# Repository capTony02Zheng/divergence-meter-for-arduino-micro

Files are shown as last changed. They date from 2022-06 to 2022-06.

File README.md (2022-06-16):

# divergence-meter-for-arduino-micro
 This is a project use for creating an divergence meter. Thank you for visiting.
-----------------------------------------------------------------------

 Code are well written but need the user to update the IRdata to match the 1838IR remote control. Also the ds3231 module need to be updated with
other code, which is not provided here.

 The PCB is developed with kiCAD.

 To start up from nothing, here's the few steps you need to follow:
-----------------------------------------------------------------------
 Get all the component you need, which includes:

// An arduino micro board;
// A pcb that is printed with the file provided; (this pcb is 51mm * 130mm in size)
// A ds3231 time module;
// An IR1838 module with corresponding remote control;
// One or two 5v to 170v boost module;
// multiple resistors of 10k and 100k;
// four hv5523pg-g chips; you can buy some here: https://www.microchip.com/en-us/product/hv5522#document-table;

After gathering all the component, it is time for you to do the soldering work. It is recommended to solder the 4 chips first, then the arduino board.

About the boost module:
pin "170vin1" and "170vin2" should be connected to the 170v output from the boost module. pin "5VFB" shoule be connected to the 5v input on the boost module.

About external power source(Optional):
if you decided to use other battery module to support the arduino, the pins "BatteryIn" and "BatteryGround" is provided, the supporting volts should not exceeds the the range that arduino micro can accept.

About the resistors:
It is recommended to connect 10k or 20k resistors at the pins "170V" and "170V2";
for places like "t1dp" and "t2dp", a 100k resistor is recommended.

About the pins:
you can directly connected the nixie tubes pins to the correponding hole in the pcb, like the t1n1 means tube1 number1, at displays it is the number "1" of the left most nixie tube. or you can use ph2.0 sockets with 12 pins.

Features and controls of the divergence meter:
-----------------------------------------------------------------------
There are 6 mode for the divergence meter, the first one displays current time; the second one displays current date; the third one
displays Celsius temperature recorded by ds3231; the fourth mode displays displays worldline; the fifth mode displays the number you entered;
the sixth one diplays number from 0 to 9 to protect the tubes;

//About the control:

Power: close or open;

Menu: First time you pressed you entered menu mode, then you can push button from 0 to 5 to choose corresponding mode, which will help you leave the menu mode automatically. Or at menu mode you can use arrow to go to the next or previous mode, then press menu again to exit the menu mode;

Play: At worldline mode you can use it to get in and out of random display mode; At manual input mode you can use it to open or close displays.

"-": as decimal point in manual input mode.

"C": At manual input mode you can use it to change wether the decimal point and number are display in one tube or not, which can save some spaces. At worldline mode you can change the number to be displayed one by one or all by instant.

"return": clear all the input data at the manual display mode.

left and right arrow: when at worldline mode and the menu mode is off, you can use it to display the next or previous worldline.

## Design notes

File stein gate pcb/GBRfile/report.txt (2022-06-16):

Plotted to '/Users/zzh/Desktop/kicad project/stein gate pcb/GBRfile/stein gate pcb-F_Cu.gbr'.
Plotted to '/Users/zzh/Desktop/kicad project/stein gate pcb/GBRfile/stein gate pcb-B_Cu.gbr'.
Plotted to '/Users/zzh/Desktop/kicad project/stein gate pcb/GBRfile/stein gate pcb-F_Paste.gbr'.
Plotted to '/Users/zzh/Desktop/kicad project/stein gate pcb/GBRfile/stein gate pcb-B_Paste.gbr'.
Plotted to '/Users/zzh/Desktop/kicad project/stein gate pcb/GBRfile/stein gate pcb-F_Silkscreen.gbr'.
Plotted to '/Users/zzh/Desktop/kicad project/stein gate pcb/GBRfile/stein gate pcb-B_Silkscreen.gbr'.
Plotted to '/Users/zzh/Desktop/kicad project/stein gate pcb/GBRfile/stein gate pcb-F_Mask.gbr'.
Plotted to '/Users/zzh/Desktop/kicad project/stein gate pcb/GBRfile/stein gate pcb-B_Mask.gbr'.
Plotted to '/Users/zzh/Desktop/kicad project/stein gate pcb/GBRfile/stein gate pcb-Edge_Cuts.gbr'.
Created Gerber job file '/Users/zzh/Desktop/kicad project/stein gate pcb/GBRfile/stein gate pcb-job.gbrjob'.
Info: Done.

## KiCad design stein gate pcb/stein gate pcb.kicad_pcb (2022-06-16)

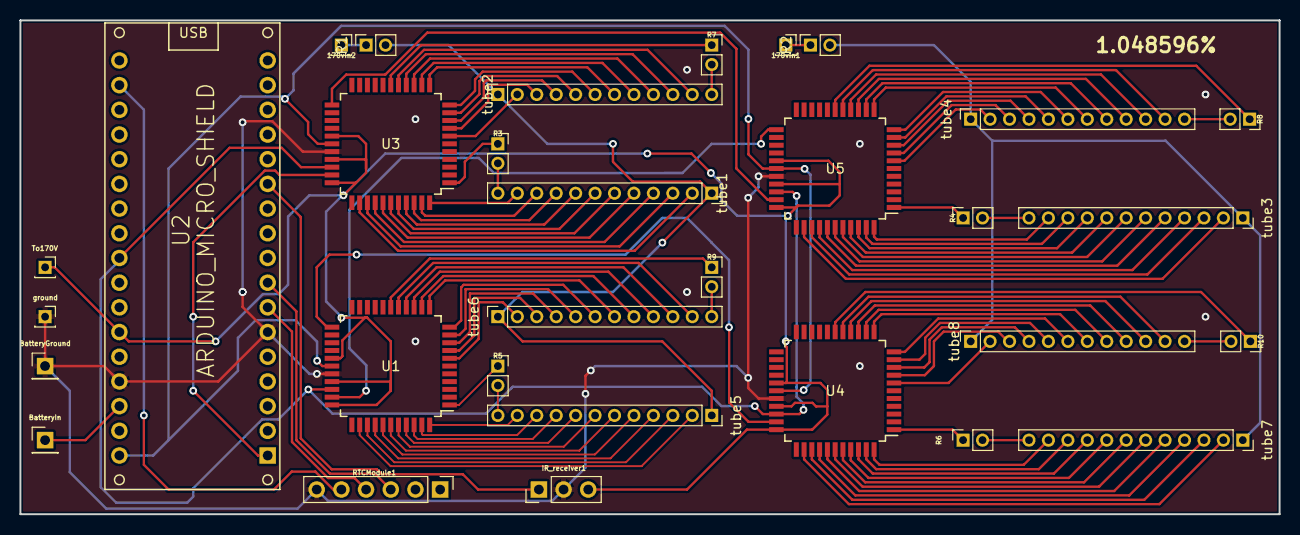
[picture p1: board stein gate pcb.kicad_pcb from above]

Board: 2 copper layers, 129.5 x 50.8 mm, 31 parts (0 on the bottom side), 113 nets.

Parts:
170vin1, 170vin2: Conn_01x01_Female; PinSocket_1x01_P2.00mm_Vertical
BatteryGround: Conn_01x01_Female; PinHeader_1x01_P2.54mm_Vertical
BatteryIn: Conn_01x01_Female; PinHeader_1x01_P2.54mm_Vertical
IR_receiver1: Conn_01x03_Female; PinHeader_1x03_P2.54mm_Vertical
R1, R2, R3, R4, R5, R6, R7, R8, R9, R10: R; PinSocket_1x02_P2.00mm_Vertical
RTCModule1: Conn_01x06_Female; PinHeader_1x06_P2.54mm_Vertical
To170V: Conn_01x01_Female; PinSocket_1x01_P2.00mm_Vertical
U1, U3, U4, U5: hv5522(first_created); PQFP-44_10x10mm_P0.8mm
U2: ARDUINO_MICRO_SHIELD
ground: Conn_01x01_Female; PinSocket_1x01_P2.00mm_Vertical
tube1, tube2, tube3, tube4, tube5, tube6, tube7, tube8: ph2.0_terminal_for_5440; PinSocket_1x12_P2.00mm_Vertical

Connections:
/3.3VFB: RTCModule1.5, U2.3.3V
/5VFB: IR_receiver1.3, To170V.1, U1.27 (POL), U1.30 (VDD), U1.33 (BL), U2.5V (+5V), U3.27 (POL), U3.30 (VDD), U3.33 (BL), U4.27 (POL), U4.30 (VDD), U4.33 (BL), U5.27 (POL), U5.30 (VDD), U5.33 (BL)
/170V: R2.2, tube3.1, tube4.1, tube7.1, tube8.1
/170V2: R1.2, tube1.1, tube2.1, tube5.1, tube6.1
/Clock: U1.28 (CLK), U2.SCK, U3.28 (CLK), U4.28 (CLK), U5.28 (CLK)
/DataFromBoard: U2.MO (MOSI), U3.32 (Data_in)
/IRdata: IR_receiver1.1, U2.7
/SCL: RTCModule1.3, U2.3 (3(PWM)/SCL)
/SDA: RTCModule1.4, U2.2 (2/SDA)
/dataout1: U3.23 (Data_out), U5.32 (Data_in)
/dataout2: U1.32 (Data_in), U5.23 (Data_out)
/dataout3: U1.23 (Data_out), U4.32 (Data_in)
/latch: U1.31 (Latch_), U2.A5, U3.31 (Latch_), U4.31 (Latch_), U5.31 (Latch_)
/t1dp: R3.1, U3.1 (HVOUT_11)
/t1n0: U3.44 (HVOUT_10), tube1.11
/t1n1: U3.35 (HVOUT_1), tube1.2
/t1n2: U3.36 (HVOUT_2), tube1.3
/t1n3: U3.37 (HVOUT_3), tube1.4
/t1n4: U3.38 (HVOUT_4), tube1.5
/t1n5: U3.39 (HVOUT_5), tube1.6
/t1n6: U3.40 (HVOUT_6), tube1.7
/t1n7: U3.41 (HVOUT_7), tube1.8
/t1n8: U3.42 (HVOUT_8), tube1.9
/t1n9: U3.43 (HVOUT_9), tube1.10
/t2dp: R7.1, U3.17 (HVOUT_27)
/t2n0: U3.16 (HVOUT_26), tube2.11
/t2n1: U3.7 (HVOUT_17), tube2.2
/t2n2: U3.8 (HVOUT_18), tube2.3
/t2n3: U3.9 (HVOUT_19), tube2.4
/t2n4: U3.10 (HVOUT_20), tube2.5
/t2n5: U3.11 (HVOUT_21), tube2.6
/t2n6: U3.12 (HVOUT_22), tube2.7
/t2n7: U3.13 (HVOUT_23), tube2.8
/t2n8: U3.14 (HVOUT_24), tube2.9
/t2n9: U3.15 (HVOUT_25), tube2.10
/t3dp: R4.1, U5.1 (HVOUT_11)
/t3n0: U5.44 (HVOUT_10), tube3.11
/t3n1: U5.35 (HVOUT_1), tube3.2
/t3n2: U5.36 (HVOUT_2), tube3.3
/t3n3: U5.37 (HVOUT_3), tube3.4
/t3n4: U5.38 (HVOUT_4), tube3.5
/t3n5: U5.39 (HVOUT_5), tube3.6
/t3n6: U5.40 (HVOUT_6), tube3.7
/t3n7: U5.41 (HVOUT_7), tube3.8
/t3n8: U5.42 (HVOUT_8), tube3.9
/t3n9: U5.43 (HVOUT_9), tube3.10
/t4dp: R8.1, U5.17 (HVOUT_27)
/t4n0: U5.16 (HVOUT_26), tube4.11
/t4n1: U5.7 (HVOUT_17), tube4.2
/t4n2: U5.8 (HVOUT_18), tube4.3
/t4n3: U5.9 (HVOUT_19), tube4.4
/t4n4: U5.10 (HVOUT_20), tube4.5
/t4n5: U5.11 (HVOUT_21), tube4.6
/t4n6: U5.12 (HVOUT_22), tube4.7
/t4n7: U5.13 (HVOUT_23), tube4.8
/t4n8: U5.14 (HVOUT_24), tube4.9
/t4n9: U5.15 (HVOUT_25), tube4.10
/t5dp: R5.1, U1.1 (HVOUT_11)
/t5n0: U1.44 (HVOUT_10), tube5.11
/t5n1: U1.35 (HVOUT_1), tube5.2
/t5n2: U1.36 (HVOUT_2), tube5.3
/t5n3: U1.37 (HVOUT_3), tube5.4
/t5n4: U1.38 (HVOUT_4), tube5.5
/t5n5: U1.39 (HVOUT_5), tube5.6
/t5n6: U1.40 (HVOUT_6), tube5.7
/t5n7: U1.41 (HVOUT_7), tube5.8
/t5n8: U1.42 (HVOUT_8), tube5.9
/t5n9: U1.43 (HVOUT_9), tube5.10
/t6dp: R9.1, U1.17 (HVOUT_27)
/t6n0: U1.16 (HVOUT_26), tube6.11
/t6n1: U1.7 (HVOUT_17), tube6.2
/t6n2: U1.8 (HVOUT_18), tube6.3
/t6n3: U1.9 (HVOUT_19), tube6.4
/t6n4: U1.10 (HVOUT_20), tube6.5
/t6n5: U1.11 (HVOUT_21), tube6.6
/t6n6: U1.12 (HVOUT_22), tube6.7
/t6n7: U1.13 (HVOUT_23), tube6.8
/t6n8: U1.14 (HVOUT_24), tube6.9
/t6n9: U1.15 (HVOUT_25), tube6.10
/t7dp: R6.1, U4.1 (HVOUT_11)
/t7n0: U4.44 (HVOUT_10), tube7.11
/t7n1: U4.35 (HVOUT_1), tube7.2
/t7n2: U4.36 (HVOUT_2), tube7.3
/t7n3: U4.37 (HVOUT_3), tube7.4
/t7n4: U4.38 (HVOUT_4), tube7.5
/t7n5: U4.39 (HVOUT_5), tube7.6
/t7n6: U4.40 (HVOUT_6), tube7.7
/t7n7: U4.41 (HVOUT_7), tube7.8
/t7n8: U4.42 (HVOUT_8), tube7.9
/t7n9: U4.43 (HVOUT_9), tube7.10
/t8dp: R10.1, U4.17 (HVOUT_27)
/t8n0: U4.16 (HVOUT_26), tube8.11
/t8n1: U4.7 (HVOUT_17), tube8.2
/t8n2: U4.8 (HVOUT_18), tube8.3
/t8n3: U4.9 (HVOUT_19), tube8.4
/t8n4: U4.10 (HVOUT_20), tube8.5
/t8n5: U4.11 (HVOUT_21), tube8.6
/t8n6: U4.12 (HVOUT_22), tube8.7
/t8n7: U4.13 (HVOUT_23), tube8.8
/t8n8: U4.14 (HVOUT_24), tube8.9
/t8n9: U4.15 (HVOUT_25), tube8.10
GND: BatteryGround.1, IR_receiver1.2, RTCModule1.6, U1.29 (VSS(GND)), U2.GND, U3.29 (VSS(GND)), U4.29 (VSS(GND)), U5.29 (VSS(GND)), ground.1
unnamed: 170vin1.1, R2.1
unnamed: 170vin2.1, R1.1
unnamed: BatteryIn.1, U2.VI (VIN)
unnamed: R3.2, tube1.12
unnamed: R7.2, tube2.12
unnamed: R4.2, tube3.12
unnamed: R8.2, tube4.12
unnamed: R5.2, tube5.12
unnamed: R9.2, tube6.12
unnamed: R6.2, tube7.12
unnamed: R10.2, tube8.12

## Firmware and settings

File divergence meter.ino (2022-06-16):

// By capTOZ.
// These are code worked for the divergence meter that published in github.
// For use, the ds3231 module need to be updated, which is not included in these code.
// All you need to update is the translateIR() function, you need to update the case to the corresponding button.
// 用中文就长话短说了。这是给世界线变动率探测仪的代码，ds3231时钟模块的更改时间设定请另寻代码来更新。
// 同时translateIR()这个function需要更新才可以使变动率探测仪正常接收遥控器信号。

#include <SPI.h>
#include "RTClib.h"
#include <Wire.h>
#include "IRremote.h"

#define num1 0x8000
#define num2 0x4000
#define num3 0x2000
#define num4 0x1000
#define num5 0x0800
#define num6 0x0400
#define num7 0x0200
#define num8 0x0100
#define num9 0x0080
#define num0 0x0040
#define decimalpoint 0x0020 
#define no_display 0x0000

#define num1dot 0x8020
#define num2dot 0x4020
#define num3dot 0x2020
#define num4dot 0x1020
#define num5dot 0x0820
#define num6dot 0x0420
#define num7dot 0x0220
#define num8dot 0x0120
#define num9dot 0x00A0
#define num0dot 0x0060

#define latchPin A5
#define SDA 2
#define SCL 3
#define IRdata 7


#define tDelay 1000
RTC_DS3231 rtc;
IRrecv irrecv(IRdata);
decode_results results;
int index_of_tube;
short mode;
float Worldline[65];
String todisplay;
bool decimalbind;
bool randomdisplay;
bool isopen;
bool displayopen;
bool inmenu;
bool onebyone;
short worldlineindex;
char secondforcompare; //mode 1 flag
bool dayflag; //mode1 flag
String tempforcompare; //mode2 flag
int worldlineindexforcompare; //mode3 flag
String mode4flag;


void shutdisplay() {
  spistart();
  for (int i = 0; i < 8; i++) {
      updatetube(chartoint(String(i).charAt(0)));
  }
  spiend();
  delay(tDelay);
  cleardisplay();
}

void opendisplay() {
  cleardisplay();
  delay(tDelay);
  spistart();
  for (int i = 7; i >= 0; i--) {
      updatetube(chartoint(String(i).charAt(0)));
  }
  spiend();
  delay(2000);
  cleardisplay();
  mode = 0;
  index_of_tube = 0;
  todisplay = "";
  decimalbind = false;
  randomdisplay = false;
  inmenu = false;
  secondforcompare = 'x';
  worldlineindex = 45;
  dayflag = false;
  tempforcompare = "";
  worldlineindexforcompare = -1;
  mode4flag = "null";
  isopen = true;
  onebyone = false;
}

void cleardisplay() {
  spistart();
    for (int i = 0; i < 8; i++) {
      updatetube(no_display);
    }
  spiend();
}

void blinkdisplay() {
  spistart();
    for (int i = 0; i < 8; i++) {
      updatetube(decimalpoint);
    }
  spiend();
  delay(1000);
  cleardisplay();
  dayflag = false;
  tempforcompare = "";
  worldlineindexforcompare = -1;
  mode4flag = "null";
  secondforcompare =  'x';
}

void displayoutcome() {
  if (todisplay.length() > 8) {
    spistart();
    if (decimalbind == false) {
      for (int i = todisplay.length() - 1; i > todisplay.length() - 9; i--) {
        updatetube(chartoint(todisplay.charAt(i)));
      }
    } else {
      int index = 0;
      bool havedecimal = false;
      for (int i = todisplay.length() - 1; index < 8; index++) {
        if (!havedecimal) {
          updatetube(chartoint(todisplay.charAt(i)));
        } else {
          i--;
          updatetube(chartointwithdot(todisplay.charAt(i)));
          havedecimal = false;
        }
        //check prev one
        if (i != 0) {
          if (todisplay.charAt(i - 1) == '.') {
            havedecimal = true;
          }
        }
        //end of check
        i--;
      }
    }
    spiend();
    Serial.println(todisplay);
  } else {
    //only without bind mode;
    spistart();
    int count = 0;
    for (int i = todisplay.length() - 1; i >= 0; i--) {
      updatetube(chartoint(todisplay.charAt(i)));
      count++;
    }
    for (int i = count; i < 8; i++) {
      updatetube(no_display);
    }
    spiend();
    Serial.println(todisplay);
  }
}

void translateIR() {
  switch(results.value) {
    case 16753245: Serial.println("Power");
    if (isopen) {
      isopen = !isopen;
      shutdisplay();
    } else {
      isopen = !isopen;
      opendisplay();
    }
    break;
    
    case 16769565: Serial.println("Menu"); 
    // for mode change
    inmenu = !inmenu;
    blinkdisplay();
    break;
    case 16720605: Serial.println("test"); break;
    case 16712445: Serial.println("+"); break;
    case 16761405: Serial.println("return");
    if (mode == 4 && todisplay.length() > 0) {
      todisplay = "";
    }
    break;
    case 16769055: Serial.println("<--");
      if (inmenu) {
        mode--;
        if(mode == -1) {
          mode = 5;
        }
        blinkdisplay();
        break;
      }
      if (mode == 3 && randomdisplay == false) {
        worldlineindex -= 1;
        if(worldlineindex == -1) {
          worldlineindex = 64;
        }
      }
    break;
    case 16754775: Serial.println("play");
      if (mode == 4 && todisplay.length() > 0) {
        displayopen = !displayopen;
      }
      if (mode == 3) {
        randomdisplay = !randomdisplay;
        if (randomdisplay) {
          worldlineindexforcompare = -1;
        }
      }
    break;
    case 16748655: Serial.println("-->");
      if (inmenu) {
        mode++;
        if(mode == 6) {
          mode = 0;
        }
        blinkdisplay();
        break;
      }
      if (mode == 3 && randomdisplay == false) {
        worldlineindex += 1;
        if(worldlineindex == 65) {
          worldlineindex = 0;
        }
      }
    break;
    case 16738455: Serial.println("0");
      if (inmenu) {
        mode = 0;
        inmenu = false;
        blinkdisplay();
        break;
      }
      if (mode == 4) {
        todisplay += "0";
        blinkdisplay();
      }
    break;
    case 16750695: Serial.println("-");
      if (mode == 4) {
        todisplay += ".";
        blinkdisplay();
      }
    break;
    case 16756815: Serial.println("C"); 
    if (mode == 3) {
      onebyone = !onebyone;
      blinkdisplay();
      break;
    }
    if (mode == 4) {
      decimalbind = !decimalbind;
      blinkdisplay();
    }
    break;
    case 16724175: Serial.println("1");
      if (inmenu) {
          mode = 1;
          inmenu = false;
          blinkdisplay();
          break;
        }
      if (mode == 4) {
        todisplay += "1";
        blinkdisplay();
      }
      break;
    case 16718055: Serial.println("2");
      if (inmenu) {
        mode = 2;
        inmenu = false;
        blinkdisplay();
        break;
      }
      if (mode == 4) {
        todisplay += "2";
        blinkdisplay();
      }
      break;
    case 16743045: Serial.println("3");
      if (inmenu) {
        mode = 3;
        inmenu = false;
        blinkdisplay();
        break;
      }
      if (mode == 4) {
        todisplay += "3";
        blinkdisplay();
      }
      break;
    case 16716015: Serial.println("4");
      if (inmenu) {
        mode = 4;
        inmenu = false;
        blinkdisplay();
        break;
      }
      if (mode == 4) {
        todisplay += "4";
        blinkdisplay();
      }
      break;
    case 16726215: Serial.println("5");
      if (inmenu) {
        mode = 5;
        inmenu = false;
        blinkdisplay();
        break;
      }
      if (mode == 4) {
        todisplay += "5";
        blinkdisplay();
      }
      break;
    case 16734885: Serial.println("6");
    if (mode == 4) {
      todisplay += "6";
      blinkdisplay();
    }
    break;
    case 16728765: Serial.println("7");
    if (mode == 4) {
      todisplay += "7";
      blinkdisplay();
    }
    break;
    case 16730805: Serial.println("8");
    if (mode == 4) {
      todisplay += "8";
      blinkdisplay();
    }
    break;
    case 16732845: Serial.println("9");
    if (mode == 4) {
      todisplay += "9";
      blinkdisplay();
    }
    break;

    default: 
    Serial.println(" other button : ");
    Serial.println(results.value);
    break;
  }
}

uint16_t chartoint(char i) {
  switch(i) {
    case '0': return num0;
    case '1': return num1;
    case '2': return num2;
    case '3': return num3;
    case '4': return num4;
    case '5': return num5;
    case '6': return num6;
    case '7': return num7;
    case '8': return num8;
    case '9': return num9;
    case '.': return decimalpoint;
    case 'x': return no_display;
    default: 
    return no_display;
  }
}

uint16_t chartoint(long i) {
  switch(i) {
    case 0: return num0;
    case 1: return num1;
    case 2: return num2;
    case 3: return num3;
    case 4: return num4;
    case 5: return num5;
    case 6: return num6;
    case 7: return num7;
    case 8: return num8;
    case 9: return num9;
    case 10: return decimalpoint;
    case 11: return no_display;
    default: 
    return no_display;
  }
}

uint16_t chartointwithdot(char i) {
  switch(i) {
    case '0': return num0dot;
    case '1': return num1dot;
    case '2': return num2dot;
    case '3': return num3dot;
    case '4': return num4dot;
    case '5': return num5dot;
    case '6': return num6dot;
    case '7': return num7dot;
    case '8': return num8dot;
    case '9': return num9dot;
    case '.': return decimalpoint;
    case 'x': return no_display;
    default: 
    return no_display;
  }
}

void updatetube(uint16_t data) {
   SPI.transfer16(data);
}

void spistart() {
  SPI.begin();
  digitalWrite(latchPin, LOW);
  SPI.beginTransaction(SPISettings(80000, LSBFIRST, SPI_MODE1));
}

void spiend() {
  SPI.endTransaction();
  digitalWrite(latchPin, HIGH);
  SPI.end();
}

void Initilizeworldline() {
  //https://sci-adv.cc/wiki/世界线收束范围一览
  //大部分数字后面加了个三是为了后面代码进位时不出错，当作垃圾代码就得了。
  Worldline[0] = 0.5710240;
  Worldline[1] = 0.5710150;
  Worldline[2] = 0.5232993;
  Worldline[3] = 0.4569033;
  Worldline[4] = 0.4094203;
  Worldline[5] = 0.3371873;
  Worldline[6] = 0.4094313;
  Worldline[7] = 0.4569143;
  Worldline[8] = 0.5233073;
  Worldline[9] = 0.5710463;
  Worldline[10] = 0.5710823;
  Worldline[11] = 0.5710463;
  Worldline[12] = 0.5097363;
  Worldline[13] = 0.4569233;
  Worldline[14] = 0.3373373;
  Worldline[15] = 0.3371993;
  Worldline[16] = 0.3371613;
  Worldline[17] = 0.3284033;
  Worldline[18] = 0.3345813;
  Worldline[19] = 0.0000000;
  Worldline[20] = 1.1304263;
  Worldline[21] = 1.1302053;
  Worldline[22] = 1.1302383;
  Worldline[23] = 1.1298483;
  Worldline[24] = 1.3827333;
  Worldline[25] = 1.1299543;
  Worldline[26] = 1.1436883;
  Worldline[27] = 1.0647503;
  Worldline[28] = 1.0811633;
  Worldline[29] = 1.0536493;
  Worldline[30] = 1.0647563;
  Worldline[31] = 1.0558213;
  Worldline[32] = 1.1298483;
  Worldline[33] = 1.0973023;
  Worldline[34] = 1.1235813;
  Worldline[35] = 1.1298483;
  Worldline[36] = 1.1302123;
  Worldline[37] = 1.1302053;
  Worldline[38] = 1.1302063;
  Worldline[39] = 1.1302073;
  Worldline[40] = 1.1302083;
  Worldline[41] = 1.1302093;
  Worldline[42] = 1.1302103;
  Worldline[43] = 1.1302113;
  Worldline[44] = 2.6150743;
  Worldline[45] = 1.04859613;
  Worldline[46] = 1.04932613;
  Worldline[47] = 1.048728;
  Worldline[48] = 1.048725;
  Worldline[49] = 1.114514;
  Worldline[50] = 3.3860193;
  Worldline[51] = 3.030493;
  Worldline[52] = 3.019430;
  Worldline[53] = 3.667293;
  Worldline[54] = 3.600104;
  Worldline[55] = 3.406288;
  Worldline[56] = 3.372329;
  Worldline[57] = 3.182879;
  Worldline[58] = 3.130238;
  Worldline[59] = 4.456441;
  Worldline[60] = 4.493624;
  Worldline[61] = 4.530805;
  Worldline[62] = 4.4564423;
  Worldline[63] = 4.4936233;
  Worldline[64] = 4.530806;
}

void setup() {
  // put your setup code here, to run once:
  Serial.begin(9600);
  Wire.begin();
  pinMode(latchPin, OUTPUT);
  pinMode(IRdata, INPUT);
  //
  if (! rtc.begin()) { // 若果初始化失败，则
    Serial.println("Couldn't find RTC");
    Serial.flush(); 
    abort();  // 程序停止运行
  }
  irrecv.enableIRIn(); // Start the receiver
  blinkdisplay();
  index_of_tube = 0;
  mode = 0;
  decimalbind = false;
  randomdisplay = false;
  worldlineindex = 45;
  isopen = false;
  displayopen = false;
  Initilizeworldline();
  secondforcompare = 'x';
  inmenu = false;
  opendisplay();
  dayflag = false;
  tempforcompare = "";
  worldlineindexforcompare = -1;
  mode4flag = "null";
  onebyone = false;
  delay(tDelay);
}

void loop() {
  // put your main code here, to run repeatedly:
  DateTime now = rtc.now();
  if (irrecv.decode(&results)) {
    translateIR();
    irrecv.resume();
  }
  if (isopen) {
    if (mode == 0) {
      //Serial.print("mode 0");
      //
      //mode 0 display hour minute second
      //
      char h_left;
      char h_right;
      char m_left;
      char m_right;
      char s_left;
      char s_right;
      //set hour
        h_left = String((now.hour() / 10)).charAt(0);
        h_right = String((now.hour() % 10)).charAt(0);
      // set minute
        m_left = String((now.minute() / 10)).charAt(0);
        m_right = String((now.minute() % 10)).charAt(0);
      // set second
        s_left = String((now.second() / 10)).charAt(0);
        s_right = String((now.second() % 10)).charAt(0);
      
      //start transfer
      if (now.hour() == now.minute() && now.second() == now.minute()  && now.hour() % 3 == 0) {
        mode = 5;
      }
      if (secondforcompare != s_right) {
        spistart();
        updatetube(chartoint(s_right));
        updatetube(chartoint(s_left));
        updatetube(chartoint('.'));
        updatetube(chartoint(m_right));
        updatetube(chartoint(m_left));
        updatetube(chartoint('.'));
        updatetube(chartoint(h_right));
        updatetube(chartoint(h_left));
        spiend();
        //time in serial
        Serial.print(h_left);
        Serial.print(h_right);
        Serial.print(':');
        Serial.print(m_left);
        Serial.print(m_right);
        Serial.print(':');
        Serial.print(s_left);
        Serial.println(s_right);
        Serial.print("function time: ");
        Serial.print(now.hour());
        Serial.print('-');
        Serial.print(now.minute());
        Serial.print('-');
        Serial.print(now.second());
        Serial.println();
        secondforcompare = s_right;
      }
    }
    if (mode == 1) {
      //Serial.print("mode 1");
      //
      //mode 1 display year month day
      //
      char y1, y2, y3, y4;
      char mleft, mright, dleft, dright;
         mleft = String((now.month() / 10)).charAt(0);
         mright = String((now.month() % 10)).charAt(0);
         dleft = String((now.day() / 10)).charAt(0);
         dright = String((now.day() % 10)).charAt(0);
         y1 = String((now.year() / 1000)).charAt(0);
         y2 = String((now.year() / 100)).charAt(0);
         y3 = '0';
         y4 = '2';
      if (!dayflag) {
        spistart();
        updatetube(chartoint(dright)); updatetube(chartoint(dleft));
        updatetube(chartointwithdot(mright)); updatetube(chartoint(mleft));
        updatetube(chartointwithdot(y1));
        updatetube(chartoint(y2));
        updatetube(chartoint(y3));
        updatetube(chartoint(y4));
        spiend();
          Serial.print("Month: ");
          Serial.print(mleft);
          Serial.print(mright);
          Serial.println();
          Serial.print("Day: ");
          Serial.print(dleft);
          Serial.print(dright);
          Serial.println();
          Serial.print("Year: ");
          Serial.print(y4);
          Serial.print(y3);
          Serial.print(y2);
          Serial.print(y1);
          Serial.println();
        dayflag = true;
      }
    }
    if (mode == 2) {
      Serial.print("mode 2");
      //
      //mode 2 display temperature
      //
      String temp(rtc.getTemperature());
      if (tempforcompare != temp) {
        spistart();
        for (int i = 4; i >= 0; i--) {
          updatetube(chartoint(temp.charAt(i)));
        }
        updatetube(no_display);
        updatetube(no_display);
        updatetube(no_display);
        spiend();
        tempforcompare = temp;
      }
    } 
    if (mode == 3) {
      Serial.print("mode 3");
      Serial.println();
      //
      //mode 3 display worldline stored
      //
      if (randomdisplay) {
        worldlineindex = random(65);
        spistart();
        for (int i = 5; i >= 0; i--) {
          updatetube(chartoint(random(10)));
        }
        updatetube(chartoint('.'));
        updatetube(chartoint(random(10)));
        spiend();
        delay(30);
      } else if (!onebyone) {
        //display by instant;
        if (worldlineindexforcompare != worldlineindex) {
          String toadd = String(Worldline[worldlineindex]*100000000);
          String currentline;
          if (Worldline[worldlineindex] >= 1.0) {
            currentline += toadd.substring(0,1);
            currentline += ".";
            currentline += toadd.substring(1,7);
          } else if (Worldline[worldlineindex] == 0.0) {
            currentline += "0.000000";
          } else {
            currentline += "0.";
            currentline += toadd.substring(0,6);
          }
          Serial.print("index: ");
          Serial.print(worldlineindex);
          Serial.println();
          Serial.print("currentline : ");
          Serial.print(currentline);
          Serial.println();
          spistart();
          for (int i = 7; i >= 0; i--) {
            updatetube(chartoint(currentline[i]));
          }
          spiend();
          worldlineindexforcompare = worldlineindex;
        }
      } else {
        //display the number from left to right
        if (worldlineindexforcompare != worldlineindex) {
          String toadd = String(Worldline[worldlineindex]*100000000);
          String currentline;
          if (Worldline[worldlineindex] >= 1.0) {
            currentline += toadd.substring(0,1);
            currentline += ".";
            currentline += toadd.substring(1,7);
          } else if (Worldline[worldlineindex] == 0.0) {
            currentline += "0.000000";
          } else {
            currentline += "0.";
            currentline += toadd.substring(0,6);
          }
          Serial.print("index: ");
          Serial.print(worldlineindex);
          Serial.println();
          Serial.print("currentline : ");
          Serial.print(currentline);
          Serial.println();
          
          for (int i = 6; i >= 0; i--) {
            //1.048596
            //01234567
            int numtosave = 7 - i;
            int randomcount = i;
            int r = random(15,50);
            for (int t = 0; t < r; t++) {
              spistart();
              for (int c = 0; c < randomcount; c++) {
                updatetube(chartoint(random(10)));
              }
              for (int rest = numtosave; rest >= 0; rest--) {
                updatetube(chartoint(currentline[rest]));
              }
              spiend();
              delay(30);
            }
          }
          worldlineindexforcompare = worldlineindex;
        }
      }
    }
    if (mode == 4) {
      //
      //mode 4 display input data;
      //
      if (displayopen && todisplay.length() != 0) {
        if (mode4flag != todisplay) {
          displayoutcome();
          Serial.println("mode 4");
          Serial.print("todisplay: ");
          Serial.println(todisplay);
          mode4flag = todisplay;
        }
      } else {
        cleardisplay();
        mode4flag = "null";
      }
    }
    if (mode == 5) { 
    //
    //mode 5 auto anti toxic
    //
    Serial.println("mode 5");
    spistart();
    for (int i = 0; i < 8; i++) {
      String x = String(index_of_tube);
      char input = x.charAt(0);
      updatetube(chartoint(input));
    }
    spiend();
    index_of_tube++;
    if (index_of_tube >= 10) {
      index_of_tube = 0;
      mode = 0;
    }
    delay(tDelay);
    }
  }
}
